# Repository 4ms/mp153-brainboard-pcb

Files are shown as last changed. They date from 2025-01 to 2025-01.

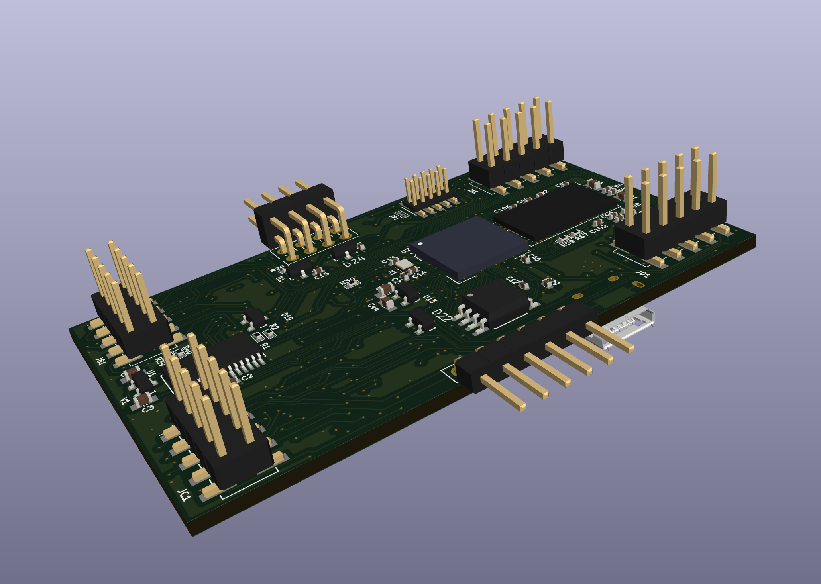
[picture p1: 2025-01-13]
assembly-images/Brainboard-mp1-mockup-2.png

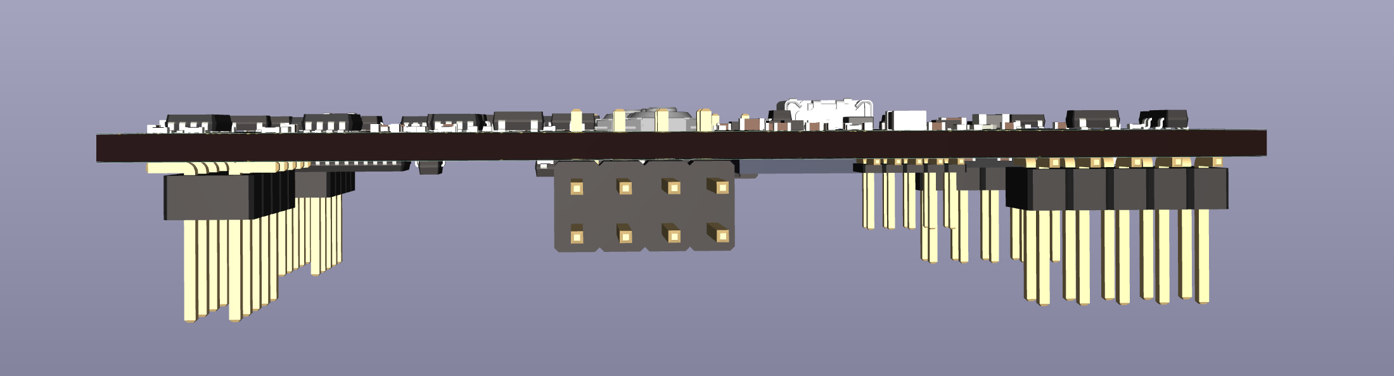
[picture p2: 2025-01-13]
assembly-images/Brainboard-mp1-mockup-4.png

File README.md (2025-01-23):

## MP153 Brainboard

This is a small PCB with an STM32MP153 microprocessor, 512MB DDR3 RAM, and a stereo codec.
It's designed for running high-end audio projects.

The processor is a dual-core Cortex-A7 at 800MHz with a 240MHz Cortex-M4 co-processor. The RAM runs up to 533MHz.
The processor supports NEON instructions, so it can be very fast for audio applications.

The brainboard is meant to plug into a larger board that has all the controls and jacks. The pinout
is similar to the Daisy Submodule, though care should be taken to confirm this before plugging into an
untested project.

Look at the schematic, under "CONNECTORS". The four 2x5 pin 0.1" headers in
that section (JA1, JB1, JC1, JD1) are the connections to your control board. 

The bare minimum connection would be to apply +12V, GND, and -12V to the appropriate pins on header JA1.
The audio inputs and outputs are on header JB1, and should be in the range of +/- 10V.

Pots or other analog inputs in the range of 0V-3.3V can be input into any ADC-IN pin (most are on JC1).
Other peripherals are available: SPI, SDMMC, UART, I2C.

The debug header is J2 and you can select SWD or JTAG. I've had better luck with JTAG, so this is the default,
but if you need to use SWD then cut the solder jumper JP1 and blob it to the NRST side.

There's an on-board USB jack, and the USB signals are on pins, so you can have a USB High Speed jack on your panel or main board (Thanks Manu!).
Don't use both at once.

For firmware, look at https://github.com/4ms/mp1-brainboard-demo and also at https://github.com/4ms/stm32mp1-baremetal

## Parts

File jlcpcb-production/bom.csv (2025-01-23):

Designator | Footprint | Quantity | Value | LCSC Part #
AN1 | Pins_1x06_P2.54mm_Horizontal_TH_CroppedSilk | 1 | Pins_01x06_RightAngle_P2.54mm_TH
C1, C19, C20, C41, C47, C48, C49 | C_0603 | 7 | 2.2uF_0603_25V | C57895
C10, C11, C8, C9 | C_0402 | 4 | 180pF_0402_25V | C106999
C100, C101, C104, C105, C107, C108, C56, C57, C58, C65, C66, C72, C75, C77, C78, C85, C86, C96, C97 | C_0402 | 19 | 100nF_0402_50V | C307331
C102, C103, C106, C12, C2, C21, C30, C40, C42, C43, C61, C64, C67, C68, C69, C82, C87, C92, C93, C94, C95, C98, C99 | C_0402 | 23 | 100nF_0402_16V | C1525
C109, C31, C33, C45, C46, C50, C51, C52, C53, C54, C55, C59, C60, C62, C63, C70, C73, C79 | C_0402 | 18 | 1uF_0402_25V | C52923
C13, C14 | C_0402 | 2 | 6.8pF_0402_25V | C1576
C15, C16, C17, C18, C24, C25, C26, C27, C28, C34, C35, C36, C37, C38, C39 | C_0402 | 15 | 10nF_0402_16V | C15195
C22, C23 | C_0402 | 2 | 220pF_0402_50V | C327000
C29, C32 | C_0402 | 2 | 2.2uF_0402_6.3V | C12530
C3, C44, C81, C83 | C_0603 | 4 | 10uF_0603_10V | C19702
C4 | C_0805 | 1 | 22uF_0805_10V | C45783
C5 | C_0603 | 1 | 0.1uF_0603_16V | C14663
C6, C7 | C_0402 | 2 | 820pF_0402_10v | C565563
C71, C74, C80 | C_0402 | 3 | 3.3nF_0402_16V | C26404
C76, C84 | C_0402 | 2 | 4.7uF_0402_6.3V | C23733
C88, C89, C90, C91 | C_0603 | 4 | 22uF_0603_6.3V | C59461
D1, D10, D12, D13, D14, D15, D16, D17, D18, D19, D2, D20, D21, D22, D23, D24, D25, D3, D4, D5, D6, D7, D8, D9 | SOT23-3_PO132 | 24 | BAT54S | C83574
D11 | DFN-1006-2 | 1 | BAT54LP | C134410
J1 | Pins_2x04_P2.54mm_Horizontal_CroppedSilk | 1 | Pins_02x04_RightAngle_P2.54mm_TH
J2 | Pins_2x05_1.27mm_SMD | 1 | Pins_02x05_P1.27mm_SMT
J3 | USB_Micro-B_Amphenol_10118194_Horizontal | 1 | USB_B_Micro_10118194-0011LF
JA1, JB1, JC1 | PinHeader_2x05_P2.54mm_Vertical_SMD | 3 | Pins_02x05_P2.54mm_SMT
JD1 | PinHeader_2x06_P2.54mm_Vertical_SMD | 1 | Conn_02x06_Odd_Even
L1, L3 | 1008 | 2 | 1uH_3.2A_2520 | C435392
L2 | L_Wuerth_MAPI-2510 | 1 | 4.7uH_1.7A_2510 | C2047781
Q1 | SOT23-3_PO132 | 1 | MMBT3904 | C20526
R1, R2 | R_0402 | 2 | 4.7k_0402 | C105871
R10, R11, R13, R14, R30, R35, R36, R37, R38, R41, R46, R47, R48, R49, R50, R51, R6, R61, R64, R66, R67, R69, R7, R72, R74, R8, R9 | R_0402 | 27 | 10k_0402 | C60490
R12, R15, R16, R17 | R_0402 | 4 | 24k_0402 | C138026
R18, R19, R26, R27, R39, R40, R70, R71 | R_0402 | 8 | 1k_0402 | C106235
R20, R21, R22, R23, R24, R25 | R_0402 | 6 | 2k_0402 | C60488
R28, R29 | R_0402 | 2 | 1M_0402 | C138033
R3 | R_0402 | 1 | 3k_0402 | C137987
R31, R32, R60, R73 | R_0402 | 4 | 100k_0402 | C60491
R33, R34 | R_0402 | 2 | 14k_0402 | C327372
R4 | R_0402 | 1 | 430k_0402 | C163463
R42, R43, R44, R45, R53, R54, R55, R56, R57, R58 | R_0402 | 10 | 68Ω_0402 | C163455
R5 | R_0402 | 1 | 620k_0402 | C137952
R52, R59 | R_0402 | 2 | 240Ω_0402 | C114755
R62 | R_0402 | 1 | 20k_0402 | C93942
R63 | R_0402 | 1 | 31.6k_0402 | C276265
R65 | R_0402 | 1 | 6.8k_0402 | C93940
R68 | R_0402 | 1 | 100Ω_0402 | C106232
S1, S2, S3 | Button_Tact_PTS526 | 3 | SW_Push_PTS526 SM15 SMTR2 LFS
U1 | TSSOP-28_4.4x9.7mm_P0.65mm | 1 | PCM3060PW
U10, U11, U12, U4, U6, U7, U8, U9 | TSSOP-8_4.4x3mm_Pitch0.65mm | 8 | NJM2068
U13 | SOT23-3_PO132 | 1 | NCP51460SN33 | C233715
U14 | FBGA-96_Layout2x3x16_Body8x14_P0.8mm | 1 | DDR3L-RAM-4Gb_MT41K256M16TW | C253882
U15, U16, U17 | SOT-563 | 3 | AP6230xZ6
U18, U19 | SOT-23-5 | 2 | TAR5S33 | C2762700
U2 | TFBGA-257_10x10mm_perP0.5_cntrP0.65 | 1 | STM32MP15xxAD | C1236719
U20 | DFN-6-1EP_2x2mm_P0.65mm_EP1x1.6mm | 1 | AP2411SN | C2149815
U3 | SOT-23-6 | 1 | USBLC6-2SC6 | C2827654
U5 | SOIC-8_5.28x4.9mm_Pitch1.27mm | 1 | NORFLASH_W25Q128JV | C113767
V1 | SOT23-3_PO132 | 1 | AP2120N-5.0TRG1
X1 | Crystal_2.0x1.6mm_4pin | 1 | 24MHz_8pF_2x1.6mm | C1986107

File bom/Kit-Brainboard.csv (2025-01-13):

4ms Company
PCBA Project: | Kit-Brainboard | Revision: | Kit-Brainboard-p5-mp1
EMAIL: | 4ms@4mscompany.com
DATE: | 2023-03-28
Group | Item# | Manufacturer | Manufacter Part# | Designator | Quantity | Designation | Package | Comments | Supplied by:
A | 1 | Murata | GRM188R6YA225KA12D | C1, C19, C20, C41, C47, C48, C49 | 7 | 2.2uF_0603_25V, 2.2uF, Min 25V 10% X5R | C0603
A | 2 | Murata | GCM155R71C104KA55D | C2, C12, C21, C30, C40, C42, C43, C61, C64, C67, C68, C69, C82, C87, C92, C93, C94, C95, C98, C99, C102, C103, C106 | 23 | 100nF_0402_16V, 0.1uF, Min. 16V 10%, X7R or X5R or similar | C0402
A | 3 | Murata | GRM188R61A106KE69D | C3, C44, C81, C83 | 4 | 10uF_0603_10V, 10uF, Min. 10V X5R 10% | C0603
A | 4 | Taiyo Yuden | LMK212BBJ226MG-T | C4 | 1 | 22uF_0805_10V, 22uF, Min. 10V, 20%, X5R or X7S or similar, 0805, MLCC | C0805
A | 5 | AVX Corporation | 0603YC104KAT2A | C5 | 1 | 0.1uF_0603_16V, 0.1uF, Min. 16V 10%, X7R or X5R or similar | C0603
A | 6 | AVX Corporation | 0402ZC821KAT2A | C6, C7 | 2 | 820pF_0402_10v, 820pF, Min. 10V 10% NP0 or C0G | C0402
A | 7 | Murata | GRM1555C2A181JE01D | C8, C9, C10, C11 | 4 | 180pF_0402_25V, 180pF, 50V, 5%, C0G or NP0 | C0402
A | 8 | Yageo | CC0402CRNPO9BN6R8 | C13, C14 | 2 | 6.8pF_0402_25V, 6.8pF, Min. 25V 10%, NP0/C0G | C0402
A | 9 | Yageo | CC0402KRX7R7BB103 | C15, C16, C17, C18, C24, C25, C26, C27, C28, C34, C35, C36, C37, C38, C39 | 15 | 10nF_0402_16V, 10nF, Min. 16V 10%, X7R or X5R or similar | C0402
A | 10 | Yageo | AC0402JPNPO9BN221 | C22, C23 | 2 | 220pF_0402_50V, 220pF, 50V, 5%, X7R or X5R or similar | C0402
A | 11 | Murata | GRM155R60J225KE95D | C29, C32 | 2 | 2.2uF_0402_6.3V, 2.2uF, Min. 6.3V 10%, X7R or X5R or similar | C0402
A | 12 | Taiyo Yuden | GMK105CC6105KV-F | C31, C33, C45, C46, C50, C51, C52, C53, C54, C55, C59, C60, C62, C63, C70, C73, C79, C109 | 18 | 1uF_0402_25V, 1uF, Min. 25V, 0402, Ceramic/MLCC | C0402
A | 13 | Murata | GRM155R71H104KE14D | C56, C57, C58, C65, C66, C72, C75, C77, C78, C85, C86, C96, C97, C100, C101, C104, C105, C107, C108 | 19 | 100nF_0402_50V, 0.1uF, Min. 50V 10%, X7R or X5R or similar | C0402
A | 14 | Vishay | VJ0402Y332KXACW1BC | C71, C74, C80 | 3 | 3.3nF_0402_16V, 3.3nF, Min. 16V 10%, X7R or X5R or similar | C0402
A | 15 | Murata | GRM155R60J475ME47 | C76, C84 | 2 | 4.7uF_0402_6.3V, 4.7uF, Min. 6.3V 20%, X7R or X5R or similar | C0402
A | 16 | Murata | GRM188R60J226MEA0J | C88, C89, C90, C91 | 4 | 22uF_0603_6.3V, 22uF, 6.3V,10%,X5R or X7R,0603 | C0603
A | 17 | Diodes Incorporated | BAT54S-7-F | D1, D2, D3, D4, D5, D6, D7, D8, D9, D10, D12, D13, D14, D15, D16, D17, D18, D19, D20, D21, D22, D23, D24, D25 | 24 | BAT54S, Dual schottky diode BAT54S | SOT23-3_PO132
A | 18 | Diodes Inc | BAT54LP-7 | D11 | 1 | BAT54LP, Schottky, 1mm x 0.6mm, Vr >= 30V, If >= 200mA, Vf = 240mA@0.1mA | DFN-1006-2
A | 19 | Murata | DFE252012P-1R0M=P2 | L1, L3 | 2 | 1uH_3.2A_2520, Inductor 1uH ~42mohm 3.2A 2.5mm x 2.0mm | L_1008_2520Metric
A | 20 | Bourns | SRN2510F-4R7M | L2 | 1 | 4.7uH_1.7A_2510, Power Inductors - SMD 4.7uH 20% SMD 2510 1.7A | L_Wuerth_MAPI-2510
A | 21 | Yageo | RC0402FR-074K7L | R1, R2 | 2 | 4.7k_0402, 4.7k, 1%, 1/16W, 0402 | R0402
A | 22 | Yageo | RC0402FR-073KL | R3 | 1 | 3k_0402, 3k, 1%, 1/16W, 0402 | R0402
A | 23 | Yageo | RC0402FR-07430KL | R4 | 1 | 430k_0402, 430k, 1%, 1/16W, 0402 | R0402
A | 24 | Yageo | RC0402FR-07620KL | R5 | 1 | 620k_0402, 620k, 1%, 1/16W, 0402 | R0402
A | 25 | Yageo | RC0402FR-0710KL | R6, R7, R8, R9, R10, R11, R13, R14, R30, R35, R36, R37, R38, R41, R46, R47, R48, R49, R50, R51, R61, R64, R66, R67, R69, R72 | 26 | 10k_0402, 10k, 1%, 1/16W, 0402 | R0402
A | 26 | Yageo | RC0402FR-0724KL | R12, R15, R16, R17 | 4 | 24k_0402, 24k, 1%, 1/16W, 0402 | R0402
A | 27 | Yageo | RC0402FR-071KL | R18, R19, R26, R27, R39, R40, R70, R71 | 8 | 1k_0402, 1k, 1%, 1/16W, 0402 | R0402
A | 28 | Yageo | RC0402FR-072KL | R20, R21, R22, R23, R24, R25 | 6 | 2k_0402, 2k, 1%, 1/16W, 0402 | R0402
A | 29 | Yageo | RC0402FR-071ML | R28, R29 | 2 | 1M_0402, 1M, 1%, 1/16W, 0402 | R0402
A | 30 | Yageo | RC0402FR-07100KL | R31, R32, R60 | 3 | 100k_0402, 100k, 1%, 1/16W, 0402 | R0402
A | 31 | Yageo | RC0402FR-0714KL | R33, R34 | 2 | 14k_0402, 14k, 1%, 1/16W, 0402 | R0402
A | 32 | Yageo | RC0402FR-0768RL | R42, R43, R44, R45, R53, R54, R55, R56, R57, R58 | 10 | 68Ω_0402, 68Ω, 1%, 1/16W, 0402 | R0402
A | 33 | Yageo | RC0402FR-07240RL | R52, R59 | 2 | 240Ω_0402, 240Ω, 1%, 1/16W, 0402 | R0402
A | 34 | Yageo | RC0402FR-0720KL | R62 | 1 | 20k_0402, 20k, 1%, 1/16W, 0402 | R0402
A | 35 | Yageo | RC0402FR-0731K6L | R63 | 1 | 31.6k_0402, 31.6k, 1%, 1/16W, 0402 | R0402
A | 36 | Yageo | RC0402FR-076K8L | R65 | 1 | 6.8k_0402, 6.8k, 1%, 1/16W, 0402 | R0402
A | 37 | Yageo | RC0402FR-07100RL | R68 | 1 | 100Ω_0402, 100Ω, 1%, 1/16W, 0402 | R0402
A | 38 | C&K Switches | PTS526 SM15 SMTR2 LFS | S1, S2, S3 | 3 | SW_Push_PTS526 SM15 SMTR2 LFS | Button_Tact_PTS526
A | 39 | Texas Instruments | PCM3060PW | U1 | 1 | PCM3060PW, Interface - CODECs 24B 96/192kHz Asynchronous Stereo | TSSOP-28_4.4x9.7mm_P0.65mm
A | 40 | STMicroelectronics | STM32MP153DAD | U2 | 1 | STM32MP15xxAD, Cortex A7x2 + M4, 800MHz, TFBGA12x12 | TFBGA-257_10x10mm_perP0.5_cntrP0.65
A | 41 | STMicroelectronics | USBLC6-2SC6 | U3 | 1 | USBLC6-2SC6, ESD Protection, pins 3+4, 1+6 shorted | SOT-23-6
A | 42 | NJR | NJM2068V-TE1 | U4, U6, U7, U8, U9, U10, U11, U12 | 8 | NJM2068 Dual Opamp | TSSOP-8_4.4x3mm_Pitch0.65mm
A | 43 | Winbond | W25Q128JVSIQ | U5 | 1 | NORFLASH_W25Q128JV, 16Mbit QSPI NOR FLASH, 4kb uniform sectors | SOIC-8_5.28x4.9mm_Pitch1.27mm
A | 44 | ON Semiconductor | NCP51460SN33T1G | U13 | 1 | NCP51460SN33, Precision 3.3V Ref 1% 18PPM 28Vmax 20mAmax | SOT23-3_PO132
A | 45 | Micron | MT41K256M16TW-107-P-V00H | U14 | 1 | DDR3L-RAM-4Gb_MT41K256M16TW, 4Gbit DDR3L | FBGA-96_Layout2x3x16_Body8x14_P0.8mm
A | 46 | Diodes Inc | AP62301Z6 | U15, U16, U17 | 3 | AP6230xZ6, 3A, 750kHz Buck DC/DC Converter, VinMax>=12V | SOT-563
A | 47 | Toshiba | TAR5S33UTE85LF | U18, U19 | 2 | TAR5S33U, LDO 3.3V, Min Vin 12V, Enable, Min Iout 50mA | SOT-563-5
A | 48 | Diodes Incorporated | AP2411SN-7 | U20 | 1 | AP2411SN | DFN-6-1EP_2x2mm_P0.65mm_EP1x1.6mm
A | 49 | Diodes Incorporated | AP2120N-5.0TRG1 | V1 | 1 | AP2120N-5.0TRG1, LDO Voltage Regulator, 5v, 150mA | SOT23-3_PO132
A | 50 | ECS | ECS-240-8-37-CKM-TR3 | X1 | 1 | 24MHz_8pF_2x1.6mm, 24MHz 8pF Crystal Resonator, 10ppm, 2016 2x1.6mm | Crystal_2.0x1.6mm_4pin
AB | 51 | Samtec | FTSH-105-01-F-DV | J2 | 1 | Pins_02x05_P1.27mm_SMT, Header 2x5 Pins, Pitch=1.27mm, Pin Height=3mm, Vertical, SMT | Pins_2x05_1.27mm_SMD
AB | 52 | Amphenol | 10118194-0011LF | J3 | 1 | USB_B_Micro_10118194-0011LF, USB Connectors MICRO USD B-TYPE | USB_Micro-B_Amphenol_10118194_Horizontal
AB | 53 | Samtec | TSM-105-01-F-DV | JA1, JB1, JC1, JD1 | 4 | Pins_02x05_P2.54mm_SMT, Header 2x5 Pins, Pitch=2.54mm, Pin Height 5.84mm, Vertical, SMT | PinHeader_2x05_P2.54mm_Vertical_SMD
B | 54 | Samtec | TSW-106-08-G-S-RA | AN1 | 1 | Pins_01x06_RightAngle_P2.54mm_TH, HEADER 1x6 MALE PINS 0.100” 90deg | Pins_1x06_P2.54mm_Horizontal_TH_CroppedSilk
B | 55 | Samtec | TSW-104-08-G-D-RA | J1 | 1 | Pins_02x04_RightAngle_P2.54mm_TH, HEADER 2x4 MALE PINS 0.100” 90deg Right Angle | Pins_2x04_P2.54mm_Horizontal_altL_CroppedSilk
D | 56 | Posin | brainboard-mp1-v1.0 | PCB1 | 1 | PCB, FR4, ENIG, 4-layer, matte black mask, white silk
D | 57 | Cixi Lanling | LL1044-1B | SJ1, SJ2 | 2 | Shunt Jumper, 2.54mm pitch, 2 position

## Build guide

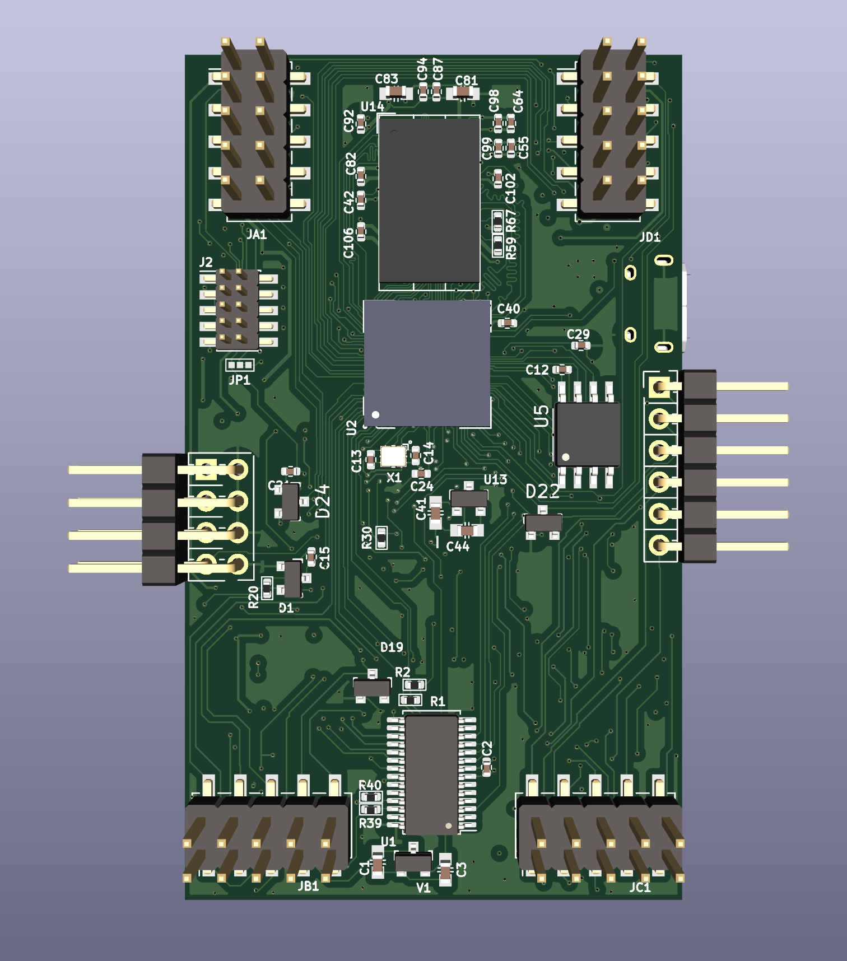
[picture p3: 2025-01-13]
assembly-images/Brainboard-mp1-mockup-1.png

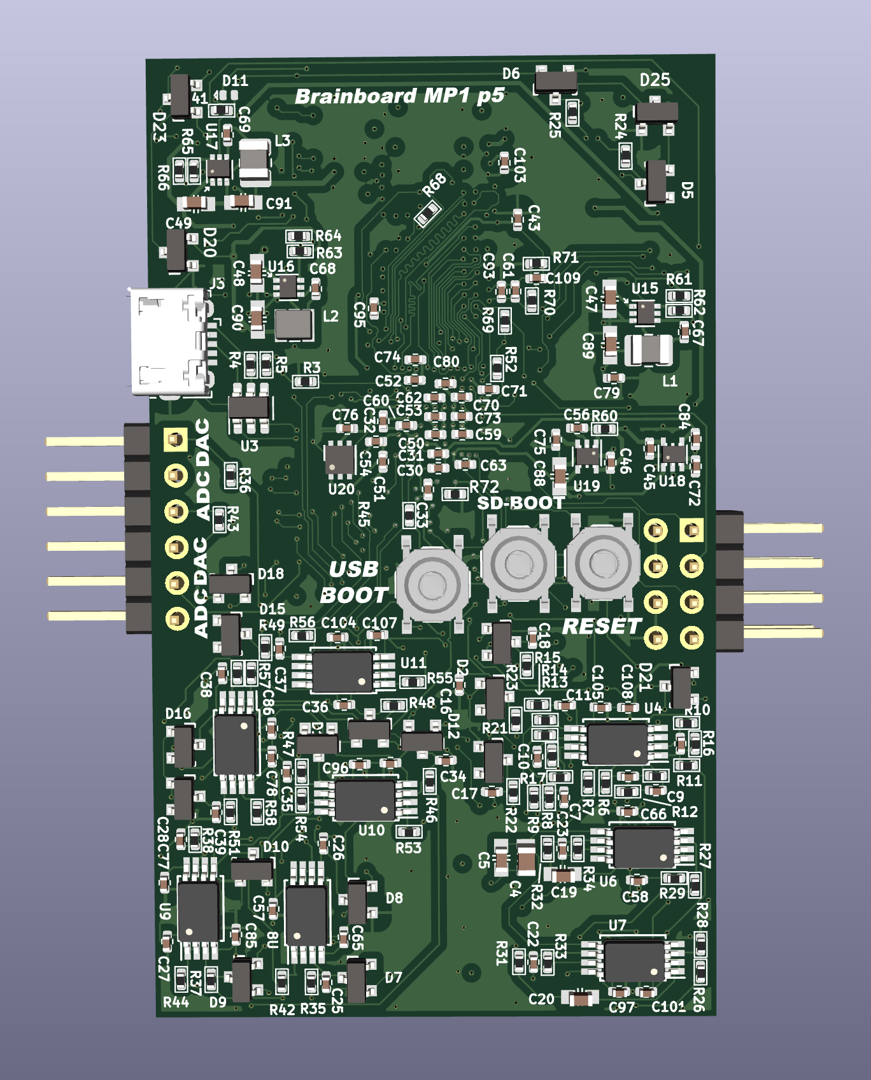
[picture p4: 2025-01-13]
assembly-images/Brainboard-mp1-mockup-3.png

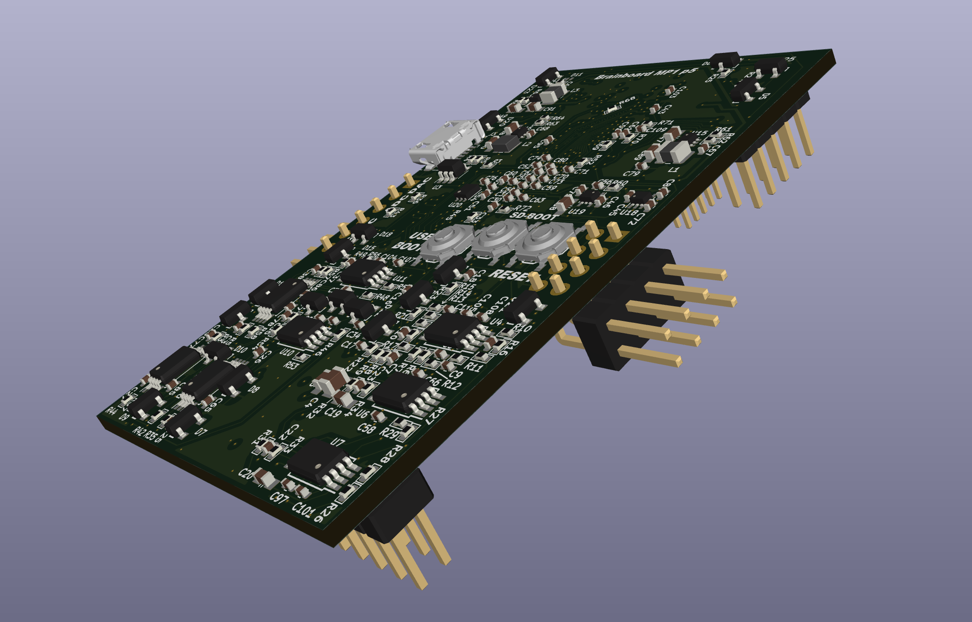
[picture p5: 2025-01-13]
assembly-images/Brainboard-mp1-mockup-5.png

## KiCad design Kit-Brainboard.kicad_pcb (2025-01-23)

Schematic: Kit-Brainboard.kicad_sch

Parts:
AN1: Pins_01x06_RightAngle_P2.54mm_TH; Pins_1x06_P2.54mm_Horizontal_TH_CroppedSilk; Part Number TSW-106-08-T-S-RA
C1, C19, C20, C41, C47, C48, C49: 2.2uF_0603_25V; C_0603; Part Number GRM188R6YA225KA12D; JLCPCB ID C57895
C2, C12, C21, C30, C40, C42, C43, C61, C64, C67, C68, C69, C82, C87, C92, C93, C94, C95, C98, C99, C102, C103, C106: 100nF_0402_16V; C_0402; Part Number GCM155R71C104KA55D; JLCPCB ID C1525
C3, C44, C81, C83: 10uF_0603_10V; C_0603; Part Number GRM188R61A106KE69D; JLCPCB ID C19702
C4: 22uF_0805_10V; C_0805; Part Number LMK212BBJ226MG-T; JLCPCB ID C45783
C5: 0.1uF_0603_16V; C_0603; Part Number 0603YC104KAT2A; JLCPCB ID C14663
C6, C7: 820pF_0402_10v; C_0402; Part Number 0402ZC821KAT2A; JLCPCB ID C565563
C8, C9, C10, C11: 180pF_0402_25V; C_0402; Part Number GRM1555C2A181JE01D; JLCPCB ID C106999
C13, C14: 6.8pF_0402_25V; C_0402; Part Number CC0402CRNPO9BN6R8; JLCPCB ID C1576
C15, C16, C17, C18, C24, C25, C26, C27, C28, C34, C35, C36, C37, C38, C39: 10nF_0402_16V; C_0402; Part Number CC0402KRX7R7BB103; JLCPCB ID C15195
C22, C23: 220pF_0402_50V; C_0402; Part Number AC0402JPNPO9BN221; JLCPCB ID C327000
C29, C32: 2.2uF_0402_6.3V; C_0402; Part Number GRM155R60J225KE95D; JLCPCB ID C12530
C31, C33, C45, C46, C50, C51, C52, C53, C54, C55, C59, C60, C62, C63, C70, C73, C79, C109: 1uF_0402_25V; C_0402; Part Number GMK105CC6105KV-F; JLCPCB ID C52923
C56, C57, C58, C65, C66, C72, C75, C77, C78, C85, C86, C96, C97, C100, C101, C104, C105, C107, C108: 100nF_0402_50V; C_0402; Part Number GRM155R71H104KE14D; JLCPCB ID C307331
C71, C74, C80: 3.3nF_0402_16V; C_0402; Part Number VJ0402Y332KXACW1BC; JLCPCB ID C26404
C76, C84: 4.7uF_0402_6.3V; C_0402; Part Number GRM155R60J475ME47; JLCPCB ID C23733
C88, C89, C90, C91: 22uF_0603_6.3V; C_0603; Part Number GRM188R60J226MEA0J; JLCPCB ID C59461
D1, D2, D3, D4, D5, D6, D7, D8, D9, D10, D12, D13, D14, D15, D16, D17, D18, D19, D20, D21, D22, D23, D24, D25: BAT54S; SOT23-3_PO132; Part Number BAT54S-7-F; JLCPCB ID C83574
D11: BAT54LP; DFN-1006-2; Part Number BAT54LP-7; JLCPCB ID C134410
J1: Pins_02x04_RightAngle_P2.54mm_TH; Pins_2x04_P2.54mm_Horizontal_CroppedSilk; Part Number TSW-104-08-T-D-RA
J2: Pins_02x05_P1.27mm_SMT; Pins_2x05_1.27mm_SMD; Part Number FTSH-105-01-F-DV
J3: USB_B_Micro_10118194-0011LF; USB_Micro-B_Amphenol_10118194_Horizontal; Part Number 10118194-0011LF
JA1: Pins_02x05_P2.54mm_SMT; PinHeader_2x05_P2.54mm_Vertical_SMD; Part Number TSM-105-01-F-DV
JB1: Pins_02x05_P2.54mm_SMT; PinHeader_2x05_P2.54mm_Vertical_SMD; Part Number TSM-105-01-F-DV
JC1: Pins_02x05_P2.54mm_SMT; PinHeader_2x05_P2.54mm_Vertical_SMD; Part Number TSM-105-01-F-DV
JD1: Conn_02x06_Odd_Even; PinHeader_2x06_P2.54mm_Vertical_SMD
JP1: SolderJumper_3_Bridged12; JUMPER_SMD_1x3_tiny
L1, L3: 1uH_3.2A_2520; L_1008_2520Metric; Part Number DFE252012P-1R0M=P2; JLCPCB ID C435392
L2: 4.7uH_1.7A_2510; L_Wuerth_MAPI-2510; Part Number SRN2510F-4R7M; JLCPCB ID C2047781
NT1, NT2: NetTie_2; NetTie-2_SMD_Pad0.16mm_6mil
PCB1: PCB; Part Number brainboard-mp1-v1.0
Q1: MMBT3904; SOT23-3_PO132; Part Number MMBT3904-TP; JLCPCB ID C20526
R1, R2: 4.7k_0402; R_0402; Part Number RC0402FR-074K7L; JLCPCB ID C105871
R3: 3k_0402; R_0402; Part Number RC0402FR-073KL; JLCPCB ID C137987
R4: 430k_0402; R_0402; Part Number RC0402FR-07430KL; JLCPCB ID C163463
R5: 620k_0402; R_0402; Part Number RC0402FR-07620KL; JLCPCB ID C137952
R6, R7, R8, R9, R10, R11, R13, R14, R30, R35, R36, R37, R38, R41, R46, R47, R48, R49, R50, R51, R61, R64, R66, R67, R69, R72, R74: 10k_0402; R_0402; Part Number RC0402FR-0710KL; JLCPCB ID C60490
R12, R15, R16, R17: 24k_0402; R_0402; Part Number RC0402FR-0724KL; JLCPCB ID C138026
R18, R19, R26, R27, R39, R40, R70, R71: 1k_0402; R_0402; Part Number RC0402FR-071KL; JLCPCB ID C106235
R20, R21, R22, R23, R24, R25: 2k_0402; R_0402; Part Number RC0402FR-072KL; JLCPCB ID C60488
R28, R29: 1M_0402; R_0402; Part Number RC0402FR-071ML; JLCPCB ID C138033
R31, R32, R60, R73: 100k_0402; R_0402; Part Number RC0402FR-07100KL; JLCPCB ID C60491
R33, R34: 14k_0402; R_0402; Part Number RC0402FR-0714KL; JLCPCB ID C327372
R42, R43, R44, R45, R53, R54, R55, R56, R57, R58: 68Ω_0402; R_0402; Part Number RC0402FR-0768RL; JLCPCB ID C163455
R52, R59: 240Ω_0402; R_0402; Part Number RC0402FR-07240RL; JLCPCB ID C114755
R62: 20k_0402; R_0402; Part Number RC0402FR-0720KL; JLCPCB ID C93942
R63: 31.6k_0402; R_0402; Part Number RC0402FR-0731K6L; JLCPCB ID C276265
R65: 6.8k_0402; R_0402; Part Number RC0402FR-076K8L; JLCPCB ID C93940
R68: 100Ω_0402; R_0402; Part Number RC0402FR-07100RL; JLCPCB ID C106232
S1, S2, S3: SW_Push_PTS526 SM15 SMTR2 LFS; Button_Tact_PTS526; Part Number PTS526 SM15 SMTR2 LFS
SJ1, SJ2: Shunt Jumper; Part Number LL1044-1B
U1: PCM3060PW; TSSOP-28_4.4x9.7mm_P0.65mm; Part Number PCM3060PW
U2: STM32MP15xxAD; TFBGA-257_10x10mm_perP0.5_cntrP0.65; Part Number STM32MP153DAD; JLCPCB ID C1236719
U3: USBLC6-2SC6; SOT-23-6; Part Number USBLC6-2SC6; JLCPCB ID C2827654
U4, U6, U7, U8, U9, U10, U11, U12: NJM2068; TSSOP-8_4.4x3mm_Pitch0.65mm; Part Number NJM2068V-TE1
U5: NORFLASH_W25Q128JV; SOIC-8_5.28x4.9mm_Pitch1.27mm; Part Number W25Q128JVSIQ; JLCPCB ID C113767
U13: NCP51460SN33; SOT23-3_PO132; Part Number NCP51460SN33T1G; JLCPCB ID C233715
U14: DDR3L-RAM-4Gb_MT41K256M16TW; FBGA-96_Layout2x3x16_Body8x14_P0.8mm; Part Number MT41K256M16TW-107-P-V00H; JLCPCB ID C253882
U15, U16, U17: AP6230xZ6; SOT-563; Part Number AP62301Z6
U18, U19: TAR5S33; SOT-23-5; Part Number TAR5S33TE85LF; JLCPCB ID C2762700
U20: AP2411SN; DFN-6-1EP_2x2mm_P0.65mm_EP1x1.6mm; Part Number AP2411SN-7; JLCPCB ID C2149815
V1: AP2120N-5.0TRG1; SOT23-3_PO132; Part Number AP2120N-5.0TRG1
X1: 24MHz_8pF_2x1.6mm; Crystal_2.0x1.6mm_4pin; Part Number ECS-240-8-37-CKM-TR3; JLCPCB ID C1986107

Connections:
+3V3: C2.1, C12.1, C90.2, D1.2 (cathode), D2.2 (cathode), D3.2 (cathode), D4.2 (cathode), D5.2 (cathode), D6.2 (cathode), D7.2 (cathode), D8.2 (cathode), D9.2 (cathode), D10.2 (cathode), D12.2 (cathode), D13.2 (cathode), D14.2 (cathode), D15.2 (cathode), D16.2 (cathode), D17.2 (cathode), D18.2 (cathode), D19.2 (cathode), D20.2 (cathode), D21.2 (cathode), D22.2 (cathode), D23.2 (cathode), D24.2 (cathode), D25.2 (cathode), L2.2, R1.2, R2.2, R63.2, U1.7 (VDD), U5.8 (VCC)
+5VA: C3.1, U1.24 (VCC), V1.2 (VO)
+12V: C1.1, C41.1, C45.2, C46.2, C47.2, C48.2, C49.2, C57.1, C58.1, C77.1, C78.1, C96.1, C97.1, C104.1, C105.1, JA1.9, R60.1, U4.8 (V+), U6.8 (V+), U7.8 (V+), U8.8 (V+), U9.8 (V+), U10.8 (V+), U11.8 (V+), U12.8 (V+), U13.1 (VI), U15.1 (VIN), U16.1 (VIN), U17.1 (VIN), U18.5 (IN), U19.5 (IN), V1.3 (VI)
-12VA: C65.1, C66.1, C85.1, C86.1, C100.1, C101.1, C107.1, C108.1, JA1.1, U4.4 (V-), U6.4 (V-), U7.4 (V-), U8.4 (V-), U9.4 (V-), U10.4 (V-), U11.4 (V-), U12.4 (V-)
/A0: AN1.5, U2.1J1 (PA4)
/A1: AN1.2, U2.1H1 (PA5)
/A2: R44.2, U2.T3 (PA2)
/A3: R45.2, U2.W3 (PA6)
/A4: R53.2, U2.N2 (PA3)
/A5: R54.2, U2.W2 (PA7)
/A6: R55.2, U2.U2 (PB0)
/A7: R56.2, U2.V1 (PC5)
/A8: R57.2, U2.P3 (PC3)
/A9: R58.2, U2.U4 (PC0)
/ADC-IN0_DAC-OUT0: JC1.1, R35.1
/ADC-IN1_DAC-OUT1: JC1.2, R36.1
/ADC-IN2: JC1.3, R37.1
/ADC-IN3: JC1.4, R38.1
/ADC-IN4: JC1.5, R46.1
/ADC-IN5: JC1.6, R47.1
/ADC-IN6: JC1.7, R48.1
/ADC-IN7: JC1.8, R49.1
/ADC-IN8: JC1.9, R50.1
/ADC-IN9: JC1.10, R51.1
/AUDIO_IN1: JB1.7, R27.2
/AUDIO_IN2: JB1.5, R26.2
/AUDIO_OUT1: JB1.3, R18.1
/AUDIO_OUT2: JB1.1, R19.1
/BOOT0: R30.2, R73.1, S1.3, S1.4, U2.H3 (BOOT0)
/BOOT2: Q1.3 (C), R74.2, U2.H1 (BOOT2)
/CODEC_RESET: U1.15 (~RST), U2.C1 (PE12)
/D0: C15.1, D1.3 (AK), R20.2, U2.C6 (PA9)
/D1: C16.1, D2.3 (AK), R21.2, U2.E3 (PE13)
/D2: C17.1, D3.3 (AK), R22.2, U2.A3 (PB7)
/D3: C18.1, D4.3 (AK), R23.2, U2.B6 (PB4)
/D4: JD1.8, U2.1A5 (PD2)
/D5: D23.3 (AK), JD1.1, U2.U15 (PA11)
/D6: D18.3 (AK), JD1.2, U2.U5 (PB10)
/D7: D22.3 (AK), JD1.6, U2.P2 (PC2)
/D8: D20.3 (AK), JD1.4, U2.T2 (PC1)
/D9: JD1.10, U2.1B4 (PC12)
/D10: D5.3 (AK), R24.2, U2.B8 (PA8)
/D11: D25.3 (AK), JA1.3, U2.U1 (PB1)
/D12: D6.3 (AK), R25.2, U2.A10 (PE4)
/D13: D19.3 (AK), JB1.8, U2.A2 (PD1)
/D14: D24.3 (AK), JA1.5, U2.T1 (PA1)
/D15: D21.3 (AK), JB1.6, U2.C5 (PD0)
/D16: JD1.9, U2.A9 (PC8)
/D17: JD1.7, U2.B9 (PC9)
/D18: JD1.5, U2.B10 (PC10)
/D19: JD1.3, U2.C11
/D-IN0: JB1.2, R20.1
/D-IN1: JB1.4, R21.1
/D-IN2: JB1.10, R22.1
/D-IN3: JB1.9, R23.1
/D-IN10: JA1.4, R24.1
/D-IN12: JA1.6, R25.1
/DDR_A0: U2.G18 (DDR_A0), U14.N3 (A0)
/DDR_A1: U2.M19 (DDR_A1), U14.P7 (A1)
/DDR_A2: U2.F17 (DDR_A2), U14.P3 (A2)
/DDR_A3: U2.F19 (DDR_A3), U14.N2 (A3)
/DDR_A4: U2.R17 (DDR_A4), U14.P8 (A4)
/DDR_A5: U2.1C9 (DDR_A5), U14.P2 (A5)
/DDR_A6: U2.1G9 (DDR_A6), U14.R8 (A6)
/DDR_A7: U2.1A9 (DDR_A7), U14.R2 (A7)
/DDR_A8: U2.T17 (DDR_A8), U14.T8 (A8)
/DDR_A9: U2.E18 (DDR_A9), U14.R3 (A9)
/DDR_A10: U2.M17 (DDR_A10), U14.L7 (A10/AP)
/DDR_A11: U2.N19 (DDR_A11), U14.R7 (A11)
/DDR_A12: U2.M18 (DDR_A12), U14.N7 (A12/BC#)
/DDR_A13: U2.E17 (DDR_A13), U14.T3 (A13)
/DDR_A14: U2.N18 (DDR_A14), U14.T7 (A14)
/DDR_BA0: U2.G19 (DDR_BA0), U14.M2 (BA0)
/DDR_BA1: U2.P18 (DDR_BA1), U14.N8 (BA1)
/DDR_BA2: U2.H17 (DDR_BA2), U14.M3 (BA2)
/DDR_CASN: U2.J19 (DDR_CASN), U14.K3 (CAS#)
/DDR_CKE: R67.2, U2.P17 (DDR_CKE), U14.K9 (CKE)
/DDR_CLK_N: R68.2, U2.K18 (DDR_CLKN), U14.K7 (CK#)
/DDR_CLK_P: R68.1, U2.L17 (DDR_CLKP), U14.J7 (CK)
/DDR_CSN: U2.J17 (DDR_CSN), U14.L2 (CS#)
/DDR_DQ0: U2.A17 (DDR_DQ0), U14.C3 (DQU1)
/DDR_DQ1: U2.A18 (DDR_DQ1), U14.C2 (DQU3)
/DDR_DQ2: U2.C18 (DDR_DQ2), U14.A7 (DQU4)
/DDR_DQ3: U2.B16 (DDR_DQ3), U14.A3 (DQU7)
/DDR_DQ4: U2.D18 (DDR_DQ4), U14.B8 (DQU6)
/DDR_DQ5: U2.D19 (DDR_DQ5), U14.C8 (DQU2)
/DDR_DQ6: U2.C19 (DDR_DQ6), U14.D7 (DQU0)
/DDR_DQ7: U2.B17 (DDR_DQ7), U14.A2 (DQU5)
/DDR_DQ8: U2.R18 (DDR_DQ8), U14.F2 (DQL2)
/DDR_DQ9: U2.U19 (DDR_DQ9), U14.E3 (DQL0)
/DDR_DQ10: U2.T19 (DDR_DQ10), U14.G2 (DQL6)
/DDR_DQ11: U2.W18 (DDR_DQ11), U14.F7 (DQL1)
/DDR_DQ12: U2.W17 (DDR_DQ12), U14.H8 (DQL5)
/DDR_DQ13: U2.T18 (DDR_DQ13), U14.H3 (DQL4)
/DDR_DQ14: U2.U17 (DDR_DQ14), U14.H7 (DQL7)
/DDR_DQ15: U2.V17 (DDR_DQ15), U14.F8 (DQL3)
/DDR_DQM0: U2.C17 (DDR_DQM0), U14.D3 (DMU)
/DDR_DQM1: U2.V18 (DDR_DQM1), U14.E7 (DML)
/DDR_DQS0_N: U2.B18 (DDR_DQS0N), U14.B7 (DQSU#)
/DDR_DQS0_P: U2.B19 (DDR_DQS0P), U14.C7 (DQSU)
/DDR_DQS1_N: U2.U18 (DDR_DQS1N), U14.G3 (DQSL#)
/DDR_DQS1_P: U2.V19 (DDR_DQS1P), U14.F3 (DQSL)
/DDR_ODT: U2.H18 (DDR_ODT), U14.K1 (ODT)
/DDR_RASN: U2.1E9 (DDR_RASN), U14.J3 (RAS#)
/DDR_RESETN: R69.2, U2.C16 (DDR_RESETN), U14.T2 (RESET#)
/DDR_WEN: U2.J18 (DDR_WEN), U14.L3 (WE#)
/DEBUG2: J1.5, U2.D1 (PG12)
/DEBUG3: J1.7, U2.D2 (PE11)
/DFU_BOOT: R72.1, S3.4, U2.E1 (PD8)
/FLASH_CLK: U2.1J7 (PF10), U5.6 (CLK)
/FLASH_CS: U2.W11 (PB6), U5.1 (~CS)
/FLASH_IO0: U2.V8 (PF8), U5.5 (IO0/SI)
/FLASH_IO1: U2.V9 (PF9), U5.2 (IO1/SO)
/FLASH_IO2: U2.W7 (PF7), U5.3 (IO2/~WP)
/FLASH_IO3: U2.U10 (PF6), U5.7 (IO3/~HOLD/~RESET)
/I2C2_SCL: R1.1, U1.1 (MC/SCL/FMT), U2.B3 (PD7)
/I2C2_SDA: R2.1, U1.2 (MD/SDA/DEMP), U2.B1 (PG15)
/IN-L: R40.2, U1.25 (VINL)
/IN-R: R39.2, U1.26 (VINR)
/JTCK_SWCLK: J2.4, U2.A16 (JTCK-SWCLK)
/JTDI: J2.8, U2.B15 (JTDI)
/JTDO_SWO: J2.6, U2.A15 (JTDO-TRACESWO)
/JTMS_SWDIO: J2.2, U2.C15 (JTMS-SWDIO)
/JTRST: JP1.1 (A), U2.B14 (NJTRST)
/LIN+: R6.1, U1.20 (VOUTL+)
/LIN-: R7.1, U1.19 (VOUTL-)
/NRST: C21.2, D11.1 (K), JP1.3 (B), S2.3, S2.4, U2.E2 (NRST)
/NRST_CORE: C24.2, U2.J3 (NRST_CORE)
/PWR_ON: R41.1, U2.M2 (PWR_ON), U15.5 (EN)
/PWR_ONRST: D11.2 (A), R41.2, U16.5 (EN), U17.5 (EN)
/RIN+: R8.1, U1.18 (VOUTR+)
/RIN-: R9.1, U1.17 (VOUTR-)
/SAI_FS: U1.4 (LRCK1), U1.11 (LRCK2), U2.U14 (PD12)
/SAI_MCLK: U1.6 (SCKI1), U1.9 (SCKI2), U2.C2 (PE0)
/SAI_SCK: U1.5 (BCK1), U1.10 (BCK2), U2.U13 (PD13)
/SAI_SD_A: U1.12 (DIN), U2.U8 (PD11)
/SAI_SD_B: U1.3 (DOUT), U2.U7 (PG10)
/UART_RX: J1.3, U2.C10 (PC7)
/UART_TX: J1.1, U2.A4 (PC6)
/USB_HS_DM: U2.W10 (USB_DM2), U3.3 (I/O2)
/USB_HS_DP: U2.V10 (USB_DP2), U3.1 (I/O1)
/USB_RREF: R3.2, U2.1J8 (USB_RREF)
/USB_VBUS: R4.2, R5.1, U2.V16 (OTG_VBUS)
/USB_VBUS_JACK: J3.1 (VBUS), R4.1, U3.5 (VBUS)
/VCOM: C4.1, C5.1, U1.21 (VCOM), U6.5 (+), U7.5 (+)
GND: C2.2, C12.2, C13.1, C14.1, C15.2, C16.2, C17.2, C18.2, C21.1, C24.1, C25.2, C26.2, C27.2, C28.2, C29.1, C32.1, C34.2, C35.2, C36.2, C37.2, C38.2, C39.2, C40.1, C42.2, C43.2, C46.1, C47.1, C48.1, C49.1, C50.1, C51.1, C52.1, C53.1, C54.1, C55.1, C56.2, C57.2, C58.2, C59.1, C60.1, C61.1, C62.1, C63.1, C64.1, C65.2, C66.2, C70.1, C71.2, C73.1, C74.2, C75.2, C76.1, C77.2, C78.2, C79.1, C80.2, C81.1, C82.1, C83.1, C85.2, C86.2, C87.1, C88.1, C89.1, C90.1, C91.1, C92.2, C93.1, C94.2, C95.1, C96.2, C97.2, C98.2, C99.2, C100.2, C101.2, C102.2, C103.2, C104.2, C105.2, C106.2, C107.2, C108.2, C109.1, D1.1 (Anode), D2.1 (Anode), D3.1 (Anode), D4.1 (Anode), D5.1 (Anode), D6.1 (Anode), D7.1 (Anode), D8.1 (Anode), D9.1 (Anode), D10.1 (Anode), D12.1 (Anode), D13.1 (Anode), D14.1 (Anode), D15.1 (Anode), D16.1 (Anode), D17.1 (Anode), D18.1 (Anode), D19.1 (Anode), D20.1 (Anode), D21.1 (Anode), D22.1 (Anode), D23.1 (Anode), D24.1 (Anode), D25.1 (Anode), J1.2, J1.4, J1.6, J1.8, J2.3, J2.5, J2.9, J3.5 (GND), J3.6 (Shield), JA1.7, NT1.2, NT2.2, Q1.2 (E), R3.1, R5.2, R28.2, R29.2, R52.2, R59.1, R62.1, R64.1, R66.1, R67.1, R69.1, R71.2, R72.2, S1.1, S1.2, S2.1, S2.2, U1.8 (DGND), U1.27 (~MS/ADR/IFMD), U1.28 (MODE), U2.1A6 (VSS), U2.1B8 (VSS), U2.1C3 (VSS), U2.1C5 (VSS), U2.1C7 (VSS), U2.1D2 (VSS), U2.1D4 (VSS), U2.1D6 (VSS), U2.1E3 (VSS), U2.1E5 (VSS), U2.1E7 (VSS), U2.1F4 (VSS), U2.1F6 (VSS), U2.1G2 (VSS), U2.1G5 (VSS), U2.1G7 (VSS), U2.1H2 (VSS), U2.1H3 (VSS), U2.1H4 (VSS), U2.1H6 (VSS), U2.1H8 (VSS), U2.1J5 (VSS), U2.1J9 (VSS), U2.A1 (VSS), U2.A6 (VSS), U2.A19 (VSS), U2.C14 (VSS), U2.D17 (VSS), U2.F3 (VSS), U2.F18 (VSS), U2.G1 (VSS), U2.G17 (VSS), U2.K3 (BOOT1), U2.K17 (VSS), U2.K19 (VSS), U2.N1 (VSS), U2.N17 (VSS), U2.R19 (VSS), U2.U9 (VSS), U2.U11 (BYPASS_REG1V8), U2.W1 (VSS), U2.W5 (VSS), U2.W13 (VSS), U2.W19 (VSS), U3.2 (GND), U5.4 (GND), U14.A9 (VSS), U14.B1 (VSSQ), U14.B3 (VSS), U14.B9 (VSSQ), U14.D1 (VSSQ), U14.D8 (VSSQ), U14.E1 (VSS), U14.E2 (VSSQ), U14.E8 (VSSQ), U14.F9 (VSSQ), U14.G1 (VSSQ), U14.G8 (VSS), U14.G9 (VSSQ), U14.J2 (VSS), U14.J8 (VSS), U14.M1 (VSS), U14.M9 (VSS), U14.P1 (VSS), U14.P9 (VSS), U14.T1 (VSS), U14.T9 (VSS), U15.3 (GND), U16.3 (GND), U17.3 (GND), U19.2 (GND), U20.2 (GND), U20.7 (EP), X1.2, X1.4
GNDA: C1.2, C3.2, C4.2, C5.2, C9.1, C11.1, NT1.1, R12.1, R15.1, U1.16 (SGND), U1.22 (AGND2), U1.23 (AGND1), V1.1 (GND)
GNDADC: C30.2, C31.1, C33.1, C41.2, C44.2, C45.1, C72.2, C84.1, JA1.8, NT2.1, U2.1G1 (VSSA), U13.3 (GND), U18.2 (GND)
unnamed: AN1.1, C26.1, D8.3 (AK), R36.2, U8.5 (+)
unnamed: AN1.3, R43.2
unnamed: AN1.4, C25.1, D7.3 (AK), R35.2, U8.3 (+)
unnamed: AN1.6, R42.2
unnamed: C6.1, R6.2, R10.2, R16.2
unnamed: C6.2, R7.2, R11.2, R12.2
unnamed: C7.1, R8.2, R13.2, R17.2
unnamed: C7.2, R9.2, R14.2, R15.2
unnamed: C8.1, R16.1, R18.2, U4.1
unnamed: C10.1, R17.1, R19.2, U4.7
unnamed: C19.1, R32.2
unnamed: C20.1, R31.2
unnamed: C22.1, R33.1, R39.1, U7.7
unnamed: C23.1, R34.1, R40.1, U6.7
unnamed: C27.1, D9.3 (AK), R37.2, U9.3 (+)
unnamed: C28.1, D10.3 (AK), R38.2, U9.5 (+)
unnamed: C34.1, D12.3 (AK), R46.2, U10.3 (+)
unnamed: C35.1, D13.3 (AK), R47.2, U10.5 (+)
unnamed: C36.1, D14.3 (AK), R48.2, U11.3 (+)
unnamed: C37.1, D15.3 (AK), R49.2, U11.5 (+)
unnamed: C38.1, D16.3 (AK), R50.2, U12.3 (+)
unnamed: C39.1, D17.3 (AK), R51.2, U12.5 (+)
unnamed: J2.10, JP1.2 (C)
unnamed: Q1.1 (B), R73.2
unnamed: C13.2, U2.H2 (PH0-OSC_IN), X1.3
unnamed: C14.2, U2.J2 (PH1-OSC_OUT), X1.1
unnamed: C29.2, U2.1J6 (VDDA1V1_REG)
unnamed: R52.1, U2.1A8 (DDR_ZQ)
unnamed: C9.2, R11.1, U4.3 (+)
unnamed: C8.2, R10.1, U4.2 (-)
unnamed: C11.2, R14.1, U4.5 (+)
unnamed: C10.2, R13.1, U4.6 (-)
unnamed: R27.1, R29.1, U6.3 (+)
unnamed: C19.2, U6.1, U6.2 (-)
unnamed: C23.2, R32.1, R34.2, U6.6 (-)
unnamed: R26.1, R28.1, U7.3 (+)
unnamed: C20.2, U7.1, U7.2 (-)
unnamed: C22.2, R31.1, R33.2, U7.6 (-)
unnamed: R42.1, U8.1, U8.2 (-)
unnamed: R43.1, U8.6 (-), U8.7
unnamed: R44.1, U9.1, U9.2 (-)
unnamed: R45.1, U9.6 (-), U9.7
unnamed: R53.1, U10.1, U10.2 (-)
unnamed: R54.1, U10.6 (-), U10.7
unnamed: R55.1, U11.1, U11.2 (-)
unnamed: R56.1, U11.6 (-), U11.7
unnamed: R57.1, U12.1, U12.2 (-)
unnamed: R58.1, U12.6 (-), U12.7
unnamed: R59.2, U14.L8 (ZQ)
unnamed: C67.2, U15.4 (BST)
unnamed: R61.1, R62.2, U15.6 (FB)
unnamed: C67.1, L1.1, U15.2 (SW)
unnamed: C68.2, U16.4 (BST)
unnamed: R63.1, R64.2, U16.6 (FB)
unnamed: C68.1, L2.1, U16.2 (SW)
unnamed: C69.2, U17.4 (BST)
unnamed: R65.1, R66.2, U17.6 (FB)
unnamed: C69.1, L3.1, U17.2 (SW)
unnamed: C72.1, U18.3 (Noise)
unnamed: C56.1, R60.2, U19.1 (EN)
unnamed: C75.1, U19.3 (Noise)
USB_DM: J3.2 (D-), JD1.12, U3.4 (I/O2)
USB_DP: J3.3 (D+), JD1.11, U3.6 (I/O1)
VDD: C51.2, C54.2, C60.2, C63.2, C88.2, J2.1, R30.1, R74.1, S3.1, U2.1D1 (VBAT), U2.1E2 (VDD), U2.1F3 (VDD), U2.1G3 (VDD), U2.1G4 (VDD), U2.1J3 (VDD), U2.K2 (PDR_ON_CORE), U2.L3 (PDR_ON), U18.1 (EN), U19.4 (OUT), U20.1 (IN)
VDDA: C30.1, C31.2, C84.2, U2.1F1 (VDDA), U2.1F2 (VDDA), U18.4 (OUT)
VDDA_1V8: C32.2, U2.1H5 (VDDA1V8_REG), U20.3 (EN)
VDD_CORE: C50.2, C53.2, C59.2, C62.2, C70.2, C73.2, C79.2, C89.2, L1.2, R61.2, U2.1B3 (VDDCORE), U2.1B5 (VDDCORE), U2.1C4 (VDDCORE), U2.1C6 (VDDCORE), U2.1D3 (VDDCORE), U2.1D5 (VDDCORE), U2.1D7 (VDDCORE), U2.1E4 (VDDCORE), U2.1E6 (VDDCORE), U2.1E8 (VDDCORE), U2.1F5 (VDDCORE), U2.1F7 (VDDCORE), U2.1G6 (VDDCORE), U2.1G8 (VDDCORE)
VDD_DDR: C52.2, C55.2, C61.2, C64.2, C71.1, C74.1, C80.1, C81.2, C82.2, C83.2, C87.2, C91.2, C92.1, C93.2, C94.1, C95.2, C98.1, C99.1, C102.1, C103.1, C106.1, L3.2, R65.2, R70.1, U2.1B9 (VDDQ_DDR), U2.1D9 (VDDQ_DDR), U2.1F9 (VDDQ_DDR), U2.1H9 (VDDQ_DDR), U14.A1 (VDDQ), U14.A8 (VDDQ), U14.B2 (VDD), U14.C1 (VDDQ), U14.C9 (VDDQ), U14.D2 (VDDQ), U14.D9 (VDD), U14.E9 (VDDQ), U14.F1 (VDDQ), U14.G7 (VDD), U14.H2 (VDDQ), U14.H9 (VDDQ), U14.K2 (VDD), U14.K8 (VDD), U14.N1 (VDD), U14.N9 (VDD), U14.R1 (VDD), U14.R9 (VDD)
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

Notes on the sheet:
SPI2_SCK
ASSEMBLY
SPI2_MISO
SPI2_MOSI
TIM
UART7_TX
POWER
I2C5_SCL
SDMMC_CMD
mp153
ADC-IN10
ADC-IN11
SDMMC_D1
SDMMC_D3
-DK2: R125 not fitted
SWD PROGRAMMING
I2C5_SDA
3.3V for peripherals Rank 2 140mA max/typ (est 43mA of 12V)
CONNECTORS
ADC-IN13
1.35V and 0.65V for DDR3 Turns on after Vddcore is stable Power cycle on reset Datasheet recommends 1.5uH (AP623) or 2.2uH (AP622)
UART4_RX
SPI2_NSS
UART4_TX
SDMMC_CLK
3.3V, Rank 3 VDD3V3_USB turns on when VDDA_1V8 is present, which is powered by VDD.
UART5_RX
ANALOG FRONT END
Analog 3.3V Turns on after Vdd
To connect to VDD_DDR power plane
NOTE: 8 more 0.1uF caps are required from VDD_CORE to GND
UART7_RX
AUDIO
ADC-IN12
PROCESSOR PORTS
BRAINBOARD
SDMMC_D0
Turn-on at EN=1.5V @100k/100nF: t = 1.3ms
1.2V, Rank 2 IDDCORE_{max} = 1050mA Should be 1.34V to enable 800MHz, but seems to work ok at 1.2V? Ratio for 1.2V: 2:1 Ratio for 1.34V: 1.48:1 or 1:0.675 (14.7k/10k) Datasheet recommends 1.5uH (AP623) or 2.2uH (AP622)
SDMMC_D2

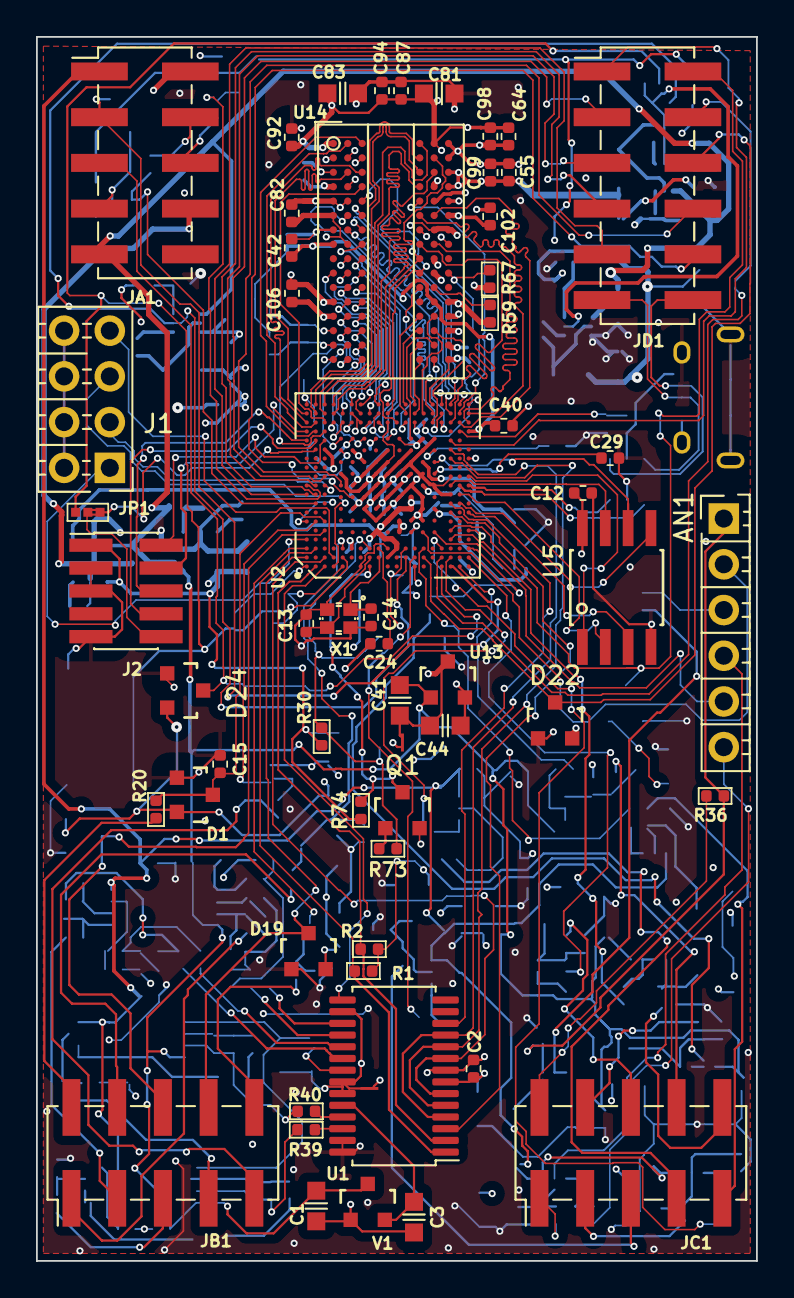
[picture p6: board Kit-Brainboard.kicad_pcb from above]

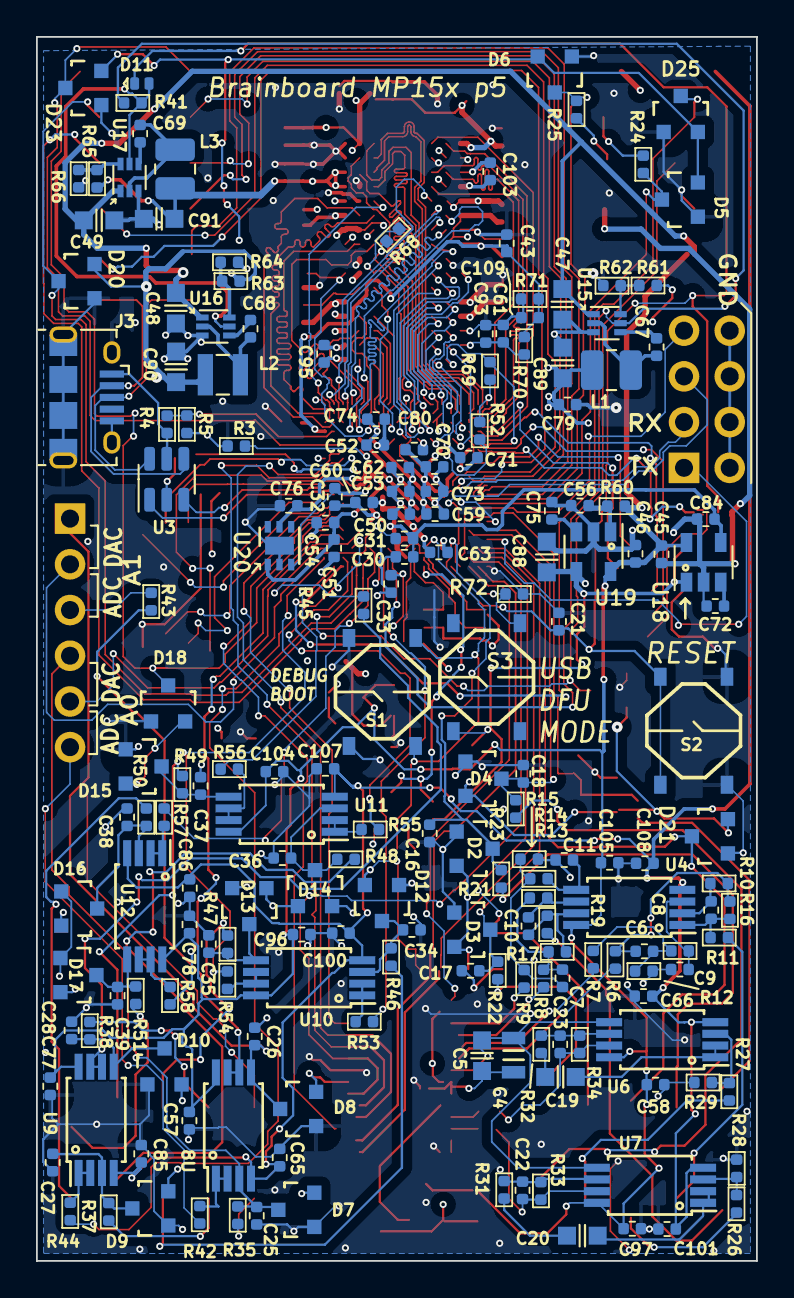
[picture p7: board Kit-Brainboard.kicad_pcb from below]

Board: 4 copper layers, 40.0 x 68.0 mm, 248 parts (190 on the bottom side), 219 nets.

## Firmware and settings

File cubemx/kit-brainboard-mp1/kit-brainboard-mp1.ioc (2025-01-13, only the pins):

Mcu.UserName=STM32MP153DADx
PA0.Signal=ADC1_INP16
PA1.Signal=ADC1_INP17
PA10.Signal=GPIO_Input
PA11.Signal=I2C5_SCL
PA12.Signal=I2C5_SDA
PA15.Signal=GPIO_Input
PA2.Signal=ADCx_INP14
PA3.Signal=ADCx_INP15
PA4.Signal=ADCx_INP18
PA5.Signal=ADCx_INP19
PA6.Signal=ADCx_INP3
PA7.Signal=ADCx_INP7
PA8.Signal=GPIO_Input
PA9.Signal=GPIO_Input
PB0.Signal=ADCx_INP9
PB1.Signal=ADCx_INP5
PB10.Signal=SPI2_SCK
PB12.Signal=SPI2_NSS
PB15.Signal=GPIO_Input
PB6.Signal=QUADSPI_BK1_NCS
PB7.Signal=GPIO_Input
PC0.Signal=ADCx_INP10
PC1.Signal=SPI2_MOSI
PC10.Signal=SDMMC1_D2
PC11.Signal=SDMMC1_D3
PC12.Signal=SDMMC1_CK
PC2.Signal=SPI2_MISO
PC3.Signal=ADCx_INP13
PC4.Signal=ADCx_INP4
PC5.Signal=ADCx_INP8
PC6.Signal=USART6_TX
PC7.Signal=USART6_RX
PC8.Signal=SDMMC1_D0
PC9.Signal=SDMMC1_D1
PD0.Signal=I2C6_SDA
PD1.Signal=I2C6_SCL
PD11.Signal=SAI2_SD_A
PD12.Signal=SAI2_FS_A
PD13.Signal=SAI2_SCK_A
PD2.Signal=SDMMC1_CMD
PE0.Signal=SAI2_MCLK_A
PE10.GPIO_Label=CodecReset
PE10.Signal=GPIO_Output
PE11.Signal=GPIO_Output
PF10.Signal=QUADSPI_CLK
PF6.Signal=QUADSPI_BK1_IO3
PF7.Signal=QUADSPI_BK1_IO2
PF8.Signal=QUADSPI_BK1_IO0
PF9.Signal=QUADSPI_BK1_IO1
PG10.Signal=SAI2_SD_B
PG8.Signal=GPIO_Output
PH0-OSC_IN.Signal=RCC_OSC_IN
PH1-OSC_OUT.Signal=RCC_OSC_OUT

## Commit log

2025-01-13 Add p5 board
    [Kit-Brainboard-B_Cu.gbr, Kit-Brainboard-B_Mask.gbr, Kit-Brainboard-B_Paste.gbr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]
2025-01-23 Added USB pins: Changed JD4 to 2x6 header
    [Kit-Brainboard.kicad_pcb, Kit-Brainboard.kicad_sch, bom.csv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]
